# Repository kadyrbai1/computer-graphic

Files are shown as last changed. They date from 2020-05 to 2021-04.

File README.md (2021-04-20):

<p align="center">
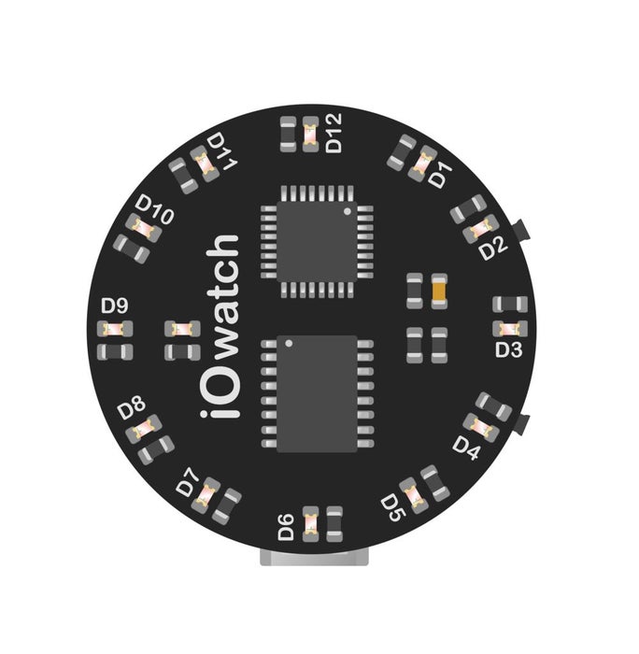
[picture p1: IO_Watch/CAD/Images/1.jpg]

</p>
<h1 align="center"><b>IO Watch</b></h3>

## ⌨️ Collaborators
- Kadyrbai Aitbaev
- Nasip Salmakhunov

## 🔗 Usefull links
- [Thingiverse](https://www.thingiverse.com/thing:4365258/files)

## Device Requirements
<h3>An overview of what components and tools were used in this build.</h3>

 - Microcontroller
  <p>The IC on this board is the ATMega328. </p>
  
 - Power system
  <p>The watch has a battery holder for a 3V, 20mm coin cell battery. Recommended 250mAh at 3V. </p>
  
 - Keeping the time
  <p>Size 0603 RED led's coupled with fairly high value (680 Ohm) resistors keeping the current low and still visible in direct sunlight. </p>
  
 - User interface
  <p>he finest RTC I can get is DS3231 keeping the time precise as it gets.  </p>
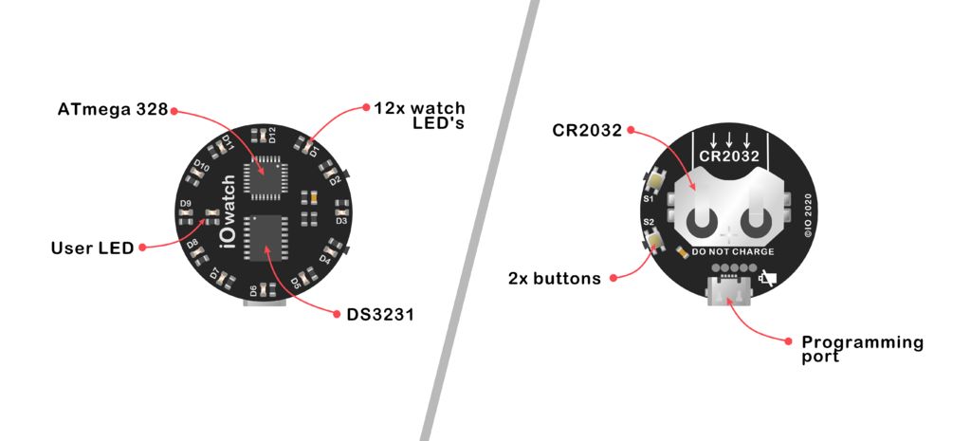
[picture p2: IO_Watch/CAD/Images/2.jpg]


## PCB - Schematics and Layout

#### PCB specifications

- Layers:2
- Dimension:35mm*35mm
- Thickness:0.8
- Impedance: no
- PCB Color: Black
- Surface Finish: HASL(with lead)
- Copper Weight:1 oz
- Gold Fingers: No
- Material Details: FR4-Standard Tg 130-140C
- Panel By JLCPCB: No
- Flying Probe Test: Fully
- Test Castellated Holes: no
<p align="center">

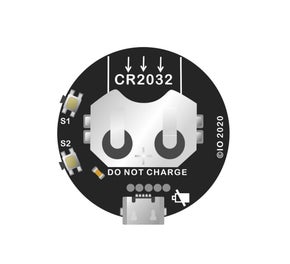
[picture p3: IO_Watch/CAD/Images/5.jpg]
 
</p>

## Programming
<p>Using the FTDI test (connection) pads provided on the back of the PCB you can use a cheap FTDI converter to upload the code.</p>
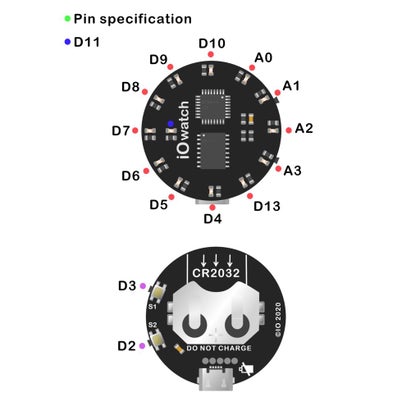
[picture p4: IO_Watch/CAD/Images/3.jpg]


## 3D Modeling and Printing
<p>verything except wrist watch band and glass - 3D prints, That includes
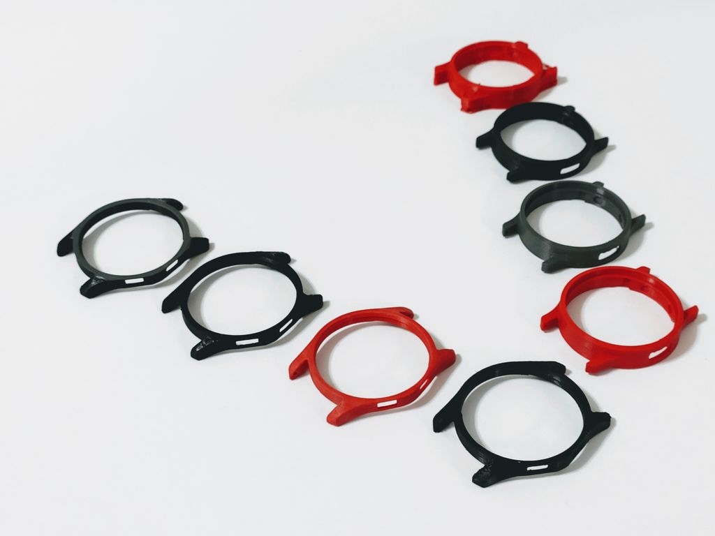
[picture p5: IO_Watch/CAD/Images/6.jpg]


- Main body
- Outer Glass ring
- Bottom body
- Buttons
I used the following settings in Cura for my prints:

- 3D Printer - Prusa I3 MK3S
- Material: PLA
- Layer Height - 0.1 mm
- Shell Thickness - 0.8 mm (Nozzle: 0.4 - 2 Shells)
- Top and Bottom Thickness - 0.8mm
- Fill Density - 100%
- Filament - 1.75mm
- Support Type - Everywhere
- Platform adhesion Type - Skirt</p>

## Circuit
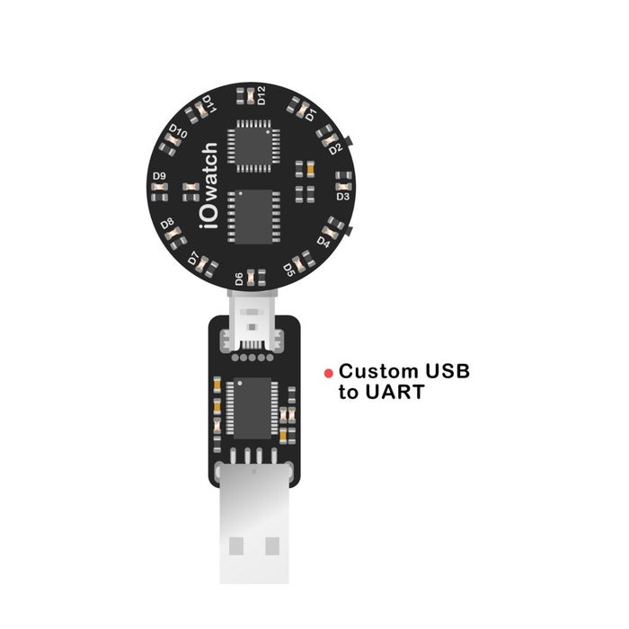
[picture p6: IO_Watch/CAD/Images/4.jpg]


## Product

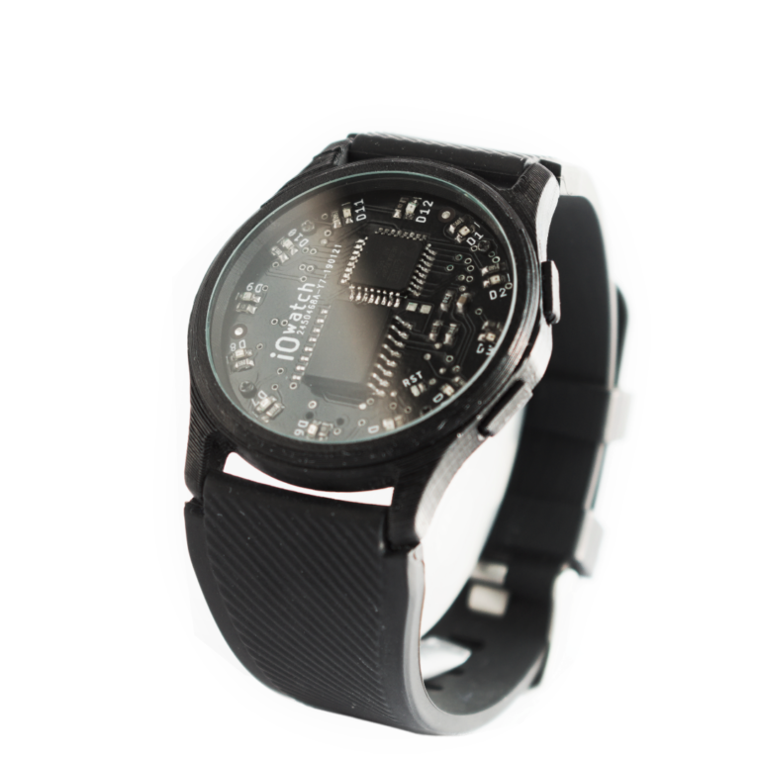
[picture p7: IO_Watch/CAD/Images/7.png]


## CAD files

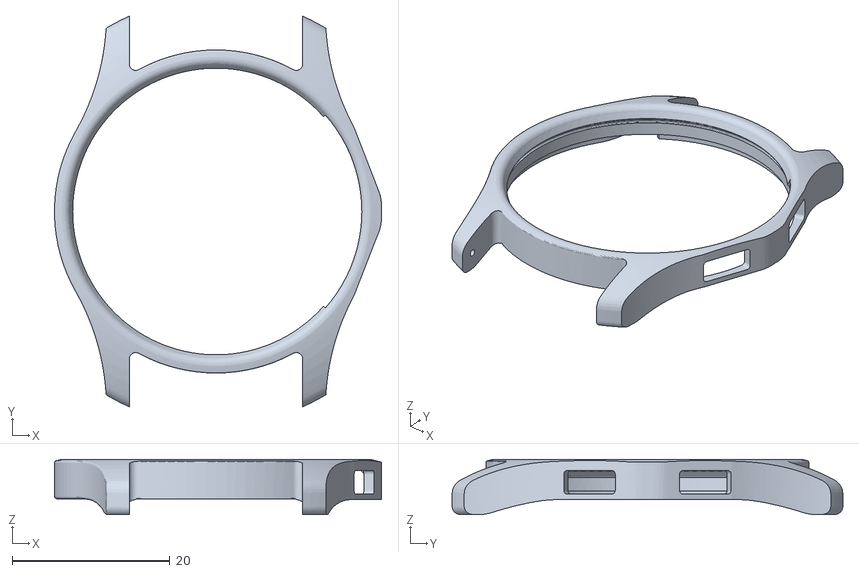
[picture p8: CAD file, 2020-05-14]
IO_Watch/CAD/Scad/imports/MainBody.stl
41.5 x 49.6 x 7.00

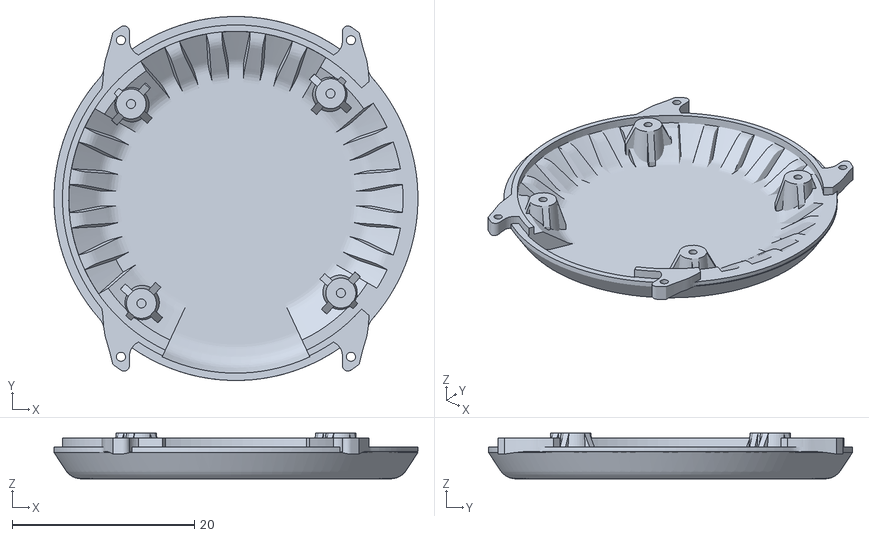
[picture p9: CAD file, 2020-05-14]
IO_Watch/CAD/Scad/imports/BottomBody.stl
40.0 x 40.0 x 5.02

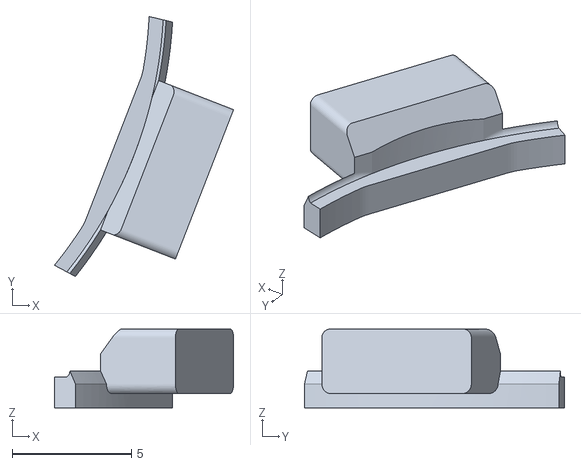
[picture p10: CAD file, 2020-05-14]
IO_Watch/CAD/Scad/imports/Button.stl
7.51 x 10.9 x 3.30

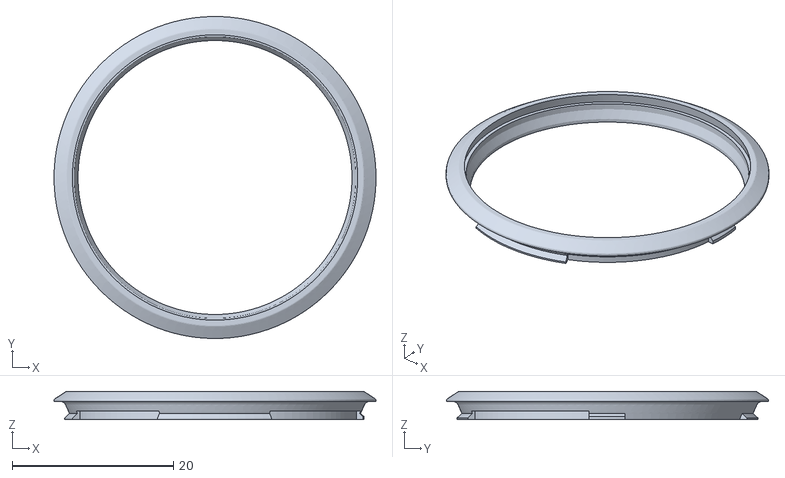
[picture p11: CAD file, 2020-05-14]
IO_Watch/CAD/Scad/imports/OuterGlassRing.stl
40.0 x 40.0 x 3.53

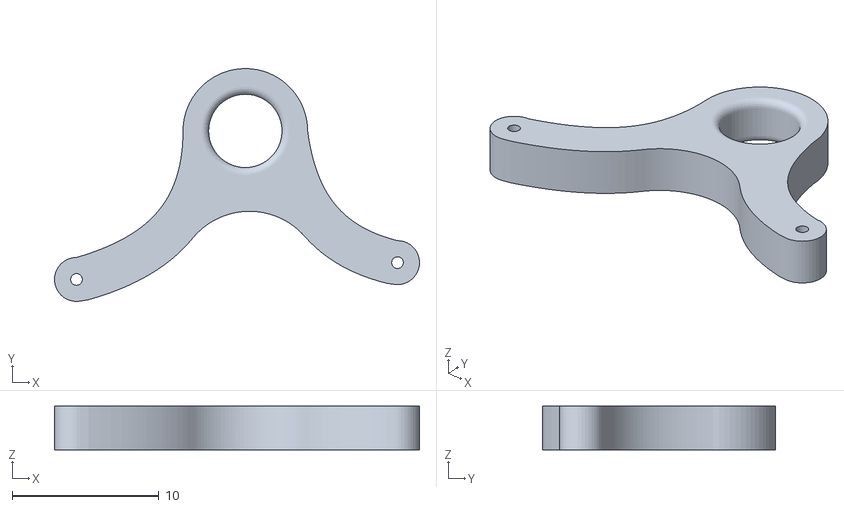
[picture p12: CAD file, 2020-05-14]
IO_Watch/CAD/Scad/imports/Badge.stl
24.9 x 15.9 x 3.00

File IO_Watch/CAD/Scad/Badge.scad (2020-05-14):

import("./imports/Badge.stl");

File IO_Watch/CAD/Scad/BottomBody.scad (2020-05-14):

import("./imports/BottomBody.stl");

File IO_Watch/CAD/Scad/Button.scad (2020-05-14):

import("Button.stl");

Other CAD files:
IO_Watch/CAD/Scad/MainBody.scad
IO_Watch/CAD/Scad/OuterGlassRing.scad

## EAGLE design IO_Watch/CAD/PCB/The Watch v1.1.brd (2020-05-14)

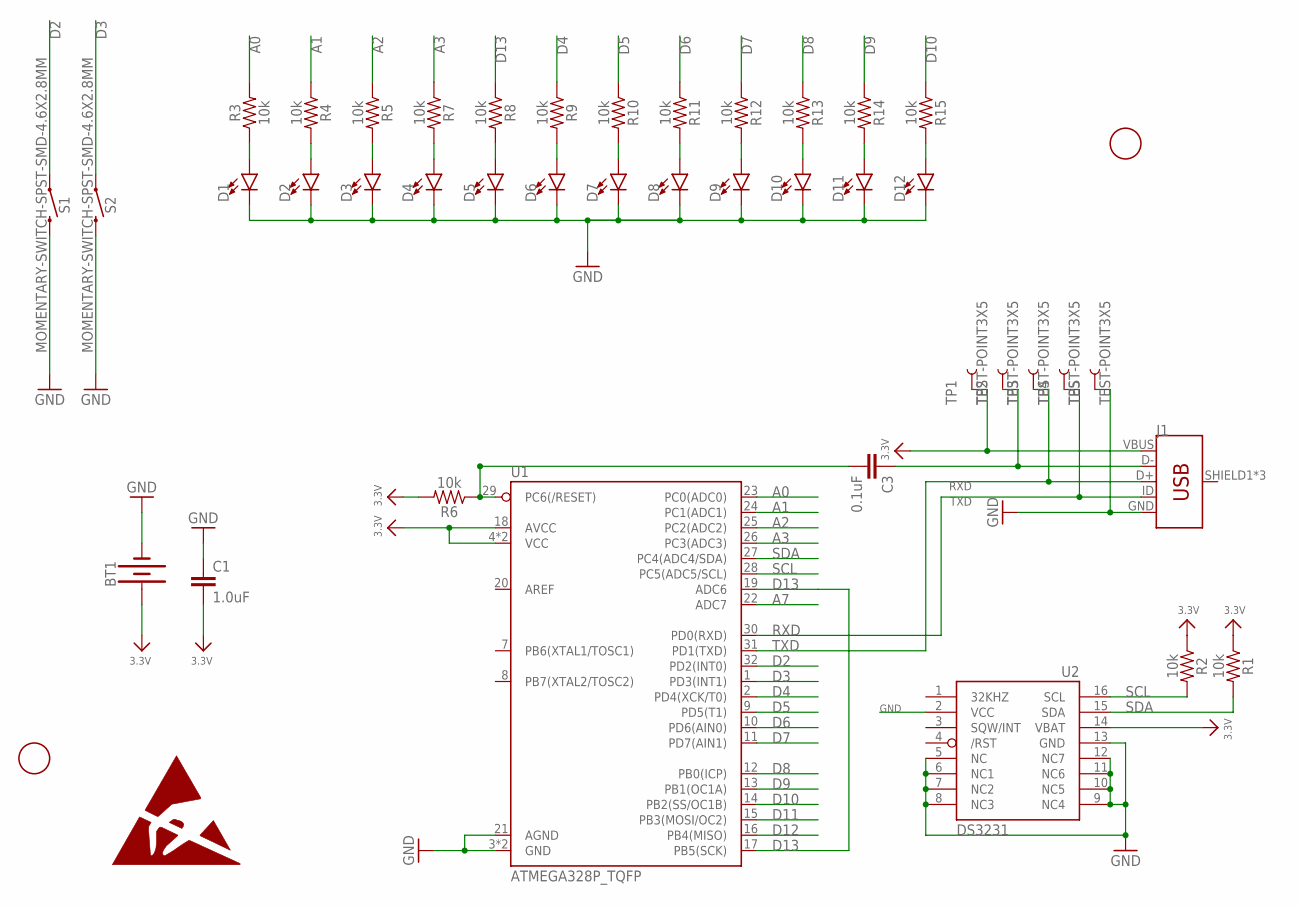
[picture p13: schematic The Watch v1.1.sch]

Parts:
BT1: BATTERY-20MM_SMD_4LEGS_OVERPASTE; BATTCON_20MM_4LEGS_OVERPASTE
C1: 1.0uF; 0603
C3: 0.1uF; 0603
D1, D2, D3, D4, D5, D6, D7, D8, D9, D10, D11, D12: LED0603; LED-0603
J1: USB_MICRO-B_FEMALE-SMT; USB-B-MICRO-SMD
R1, R2, R3, R4, R5, R6, R7, R8, R9, R10, R11, R12, R13, R14, R15: 10k; 0603
S1, S2: MOMENTARY-SWITCH-SPST-SMD-4.6X2.8MM; TACTILE_SWITCH_SMD_4.6X2.8MM
TP1, TP2, TP3, TP4, TP5: TEST-POINT3X5; PAD.03X.05
U1: ATMEGA328P_TQFP; TQFP32-08
U2: DS3231/SO; SO16W
U$1, U$10: FIDUCIAL; FIDUCIAL_1MM

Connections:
3.3V: BT1.1 (+), C1.2, J1.VBUS, R1.1, R2.1, R6.2, TP1.P$1, U1.4 (VCC), U1.6 (VCC), U1.18 (AVCC), U2.14 (VBAT)
A0: R3.2, U1.23 (PC0(ADC0))
A1: R4.1, U1.24 (PC1(ADC1))
A2: R5.1, U1.25 (PC2(ADC2))
A3: R7.1, U1.26 (PC3(ADC3))
A7: U1.22 (ADC7)
D2: S1.1, S1.2 (1), U1.32 (PD2(INT0))
D3: S2.1, S2.2 (1), U1.1 (PD3(INT1))
D4: R9.1, U1.2 (PD4(XCK/T0))
D5: R10.1, U1.9 (PD5(T1))
D6: R11.1, U1.10 (PD6(AIN0))
D7: R12.1, U1.11 (PD7(AIN1))
D8: R13.1, U1.12 (PB0(ICP))
D9: R14.1, U1.13 (PB1(OC1A))
D10: R15.1, U1.14 (PB2(SS/OC1B))
D11: U1.15 (PB3(MOSI/OC2))
D12: U1.16 (PB4(MISO))
D13: R8.1, U1.17 (PB5(SCK)), U1.19 (ADC6)
GND: BT1.2 (-), C1.1, D1.C, D2.C, D3.C, D4.C, D5.C, D6.C, D7.C, D8.C, D9.C, D10.C, D11.C, D12.C, J1.GND, S1.3 (2), S1.4 (2), S2.3 (2), S2.4 (2), TP5.P$1, U1.3 (GND), U1.5 (GND), U1.21 (AGND), U2.2 (VCC), U2.5 (NC), U2.6 (NC1), U2.7 (NC2), U2.8 (NC3), U2.9 (NC4), U2.10 (NC5), U2.11 (NC6), U2.12 (NC7), U2.13 (GND)
unnamed: D1.A, R3.1
unnamed: D2.A, R4.2
unnamed: D3.A, R5.2
unnamed: D4.A, R7.2
unnamed: D5.A, R8.2
unnamed: D6.A, R9.2
unnamed: D7.A, R10.2
unnamed: D8.A, R11.2
unnamed: D9.A, R12.2
unnamed: D10.A, R13.2
unnamed: D11.A, R14.2
unnamed: D12.A, R15.2
unnamed: C3.1, J1.D-, TP2.P$1
RESET: C3.2, R6.1, U1.29 (PC6(/RESET))
RXD: J1.ID, TP4.P$1, U1.30 (PD0(RXD))
SCL: R2.2, U1.28 (PC5(ADC5/SCL)), U2.16 (SCL)
SDA: R1.2, U1.27 (PC4(ADC4/SDA)), U2.15 (SDA)
TXD: J1.D+, TP3.P$1, U1.31 (PD1(TXD))

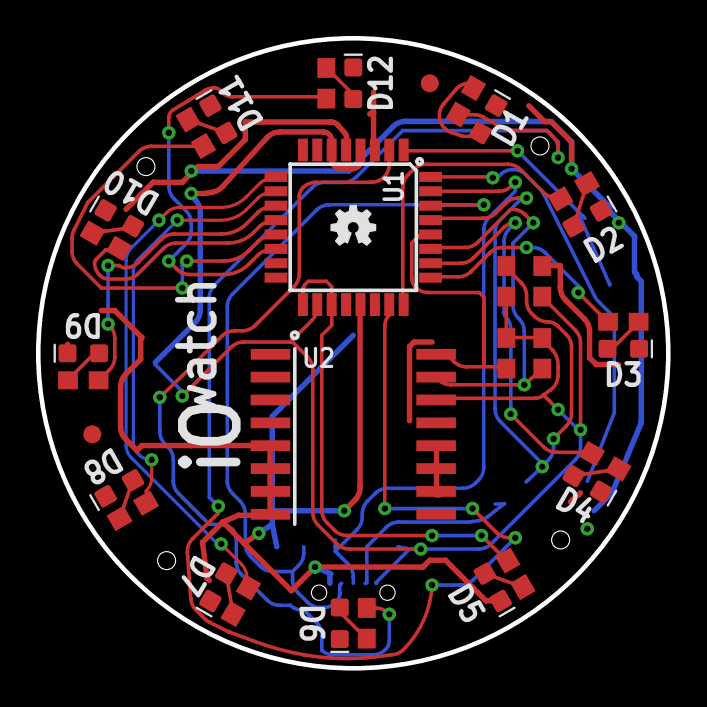
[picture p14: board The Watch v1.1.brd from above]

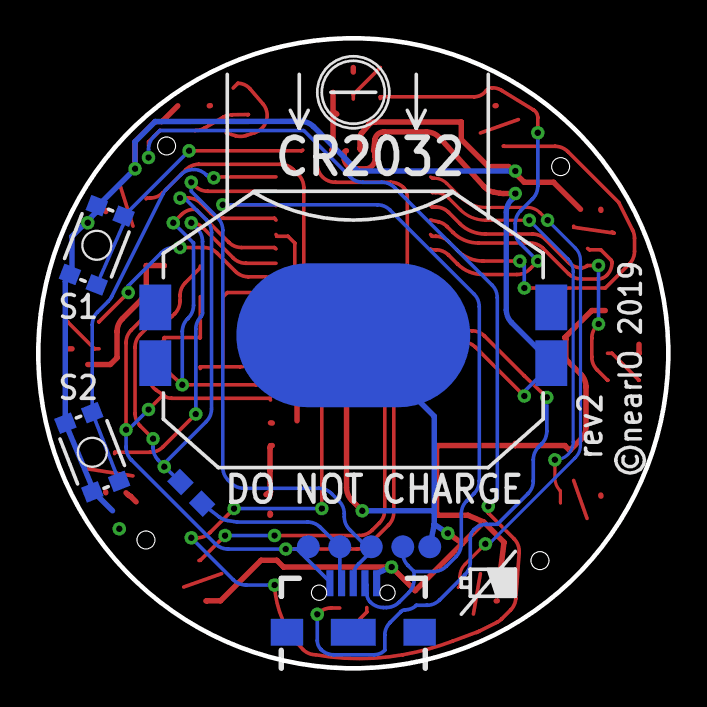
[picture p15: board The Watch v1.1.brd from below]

Board: 2 copper layers, 35.0 x 35.0 mm, 43 parts (10 on the bottom side), 34 nets.

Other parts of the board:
U$6: OSHW-LOGO-MINI

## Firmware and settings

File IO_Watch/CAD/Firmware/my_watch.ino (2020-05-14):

#include <Wire.h>                    // library for communication with I2C - DS3231
                                     // https://www.arduino.cc/en/Reference/Wire
#include "RTClib.h"                  // library for Real Time Clock
                                     // https://github.com/adafruit/RTClib.git
#include "LowPower.h"                // library for deep sleep
                                     // https://github.com/rocketscream/Low-Power.git
#include "OneButton.h"               // library for button (short press /double press /long press)
                                     // https://github.com/mathertel/OneButton.git


RTC_DS3231 rtc;                      // RealTimeClock object

byte hours;                          // hours variable       
byte minutesFive;                    // minutes variable
byte minutesOne;                     // minutes variable
byte minutesOnFive;                  // minutes variable
byte temperatures;                   // temperature variable
byte temperaturesOnFive;             // temperature variable

byte settingHours = 0;               // variable initialization
byte settingMinutes = 0;             // variable initialization
byte settingMinutesToFive = 0;       // variable initialization

const byte leds[] = {10, A0, A1, A2, A3, 13, 4, 5, 6, 7, 8, 9};  // 12 LED's array pin assigning
const byte LEDS_SIZE = sizeof(leds)/sizeof(leds[0]);

static byte buttonPin = 2;                           // assigning button pin value
static byte buttonPin2 = 3;                           // assigning button pin value

static byte userLed = 11;

boolean timeSettingMode = false;               // time setting mode
boolean timeSettingModeHours = false;          // time setting mode hours [0, 11]
boolean timeSettingModeMinutes = false;        // time setting mode minutes [0, 5, 10, .., 55]
boolean timeSettingModeMinutesToFive = false;  // time setting mode minutes [0-4]

OneButton button(3, true);      // button
OneButton button2(2, true);      // button

void setup () {
  Serial.begin(9600);         //enabling serial communication at 9600 boud rate

  //rtc.adjust(DateTime(F(__DATE__), F(__TIME__)));    // following line sets the RTC to the date & time this sketch was compiled
  rtc.adjust(DateTime(2019, 1, 1, 0, 0, 0));           //year, month, day, hour, minute, second

  for (int i=0; i<LEDS_SIZE; i++){
    pinMode(leds[i], OUTPUT);             // assigning all pins in array as output
  }
  pinMode(userLed, OUTPUT);             // assigning all pins in array as output

  allOn();          //bootup all LED's turning
  allOff();         //turning all LED's off

  delay(40);

  attachInterrupt(0, wakeFunction, FALLING);        //interrupt for waking up
  attachInterrupt(1, wakeFunction, FALLING);        //interrupt for waking up
  
  //button.attachDoubleClick(doubleclick);            // link the function to be called on a doubleclick event.
  button.attachClick(singleclick);                  // link the function to be called on a singleclick event.
  button.attachLongPressStop(longclick);            // link the function to be called on a longpress event.
  
  //button2.attachDoubleClick(doubleclick);            // link the function to be called on a doubleclick event.
  button2.attachClick(singleclick2);                  // link the function to be called on a singleclick event.
  //button2.attachLongPressStop(longclick);            // link the function to be called on a longpress event.
  
  shutdownNow();      //calling deep sleep function
}

void loop (){
  
   button.tick();     //checking if button is pressed and long
   delay(10);         //needed for stable operation and for button ticking
   button2.tick();     //checking if button 2 is pressed and long
   Serial.println("Tick");
   
}

void wakeFunction(){  //interrupt function when button is presse
  
}

void singleclick(){   //single Click button
  
 if(!timeSettingMode){

    unsigned int DelayHoursLedON = 500;           // how long will hour LED light up after getting time (in microseconds)
    unsigned int DelayHoursLedOFF = 300;          // how long will hour LED stay off after showing time (in microseconds)
    unsigned int DelayMinutesLedON = 150;         // how long will minutes LED light up after getting time in microseconds
    unsigned int DelayMinutesLedOFF = 280;        // how long will minutes LED stay off after showing time in microseconds
    
    DateTime now = rtc.now();     //gets the current time from DST

    hours = now.hour();

    minutesOne = now.minute();
    minutesFive = minutesOne/5;

    if(hours >= 12){
      hours = hours - 12;
    }
      
    digitalWrite(leds[hours],HIGH);
    delay(DelayHoursLedON);
    digitalWrite(leds[hours],LOW);
    delay(DelayHoursLedOFF);
  
    digitalWrite(leds[minutesFive],HIGH);
    delay(DelayHoursLedON);
    digitalWrite(leds[minutesFive],LOW);
    delay(DelayHoursLedOFF);
            
     minutesOnFive = minutesOne - (minutesFive * 5);
          
    for (int i=1; i <= minutesOnFive ; i++){   
       digitalWrite(leds[i], HIGH);
       delay(DelayMinutesLedOFF);
    } 
    for (int i=1; i <= minutesOnFive ; i++){       
      digitalWrite(leds[i], LOW);
      delay(DelayMinutesLedON);
    }
   shutdownNow();
 }else{
  if(timeSettingModeHours){         //hours scrolling trough LED's
    digitalWrite(leds[settingHours], LOW);
    if(settingHours == 0){
      settingHours = 11;
      digitalWrite(leds[settingHours], HIGH);
    }else{
      settingHours--;
      digitalWrite(leds[settingHours], HIGH);
    }
  }
  if(timeSettingModeMinutes){       //minutes scrolling trough LED's
    digitalWrite(leds[settingMinutes], LOW);
    if(settingMinutes == 0){
      settingMinutes = 11;
      digitalWrite(leds[settingMinutes], HIGH);
    }else{
      settingMinutes--;
      digitalWrite(leds[settingMinutes], HIGH);
    }
  }
  if(timeSettingModeMinutesToFive){       //minutes to five scrolling trough LED's
    digitalWrite(leds[settingMinutesToFive], LOW);
    if(settingMinutesToFive == 0){
      settingMinutesToFive = 4;
      digitalWrite(leds[settingMinutesToFive], HIGH);
    }else{
      settingMinutesToFive--;
      digitalWrite(leds[settingMinutesToFive], HIGH);
    }
  }
 }
}

void singleclick2(){   //single Click button
 if(!timeSettingMode){

    allOff();         //turning all LED's off

    digitalWrite(userLed, HIGH);
      
    temperatures = rtc.getTemperature();
    temperaturesOnFive = temperatures / 5;
    for (int i=0; i <= temperaturesOnFive ; i++){ 
      digitalWrite(leds[i], HIGH);
      delay(500);
    } 
    for (int i=0; i <= temperaturesOnFive ; i++){  
     digitalWrite(leds[i], LOW);
     delay(200);
    }
    delay(500);
    temperatures = temperatures - (temperaturesOnFive * 5);
    for (int i=1; i <= temperatures ; i++){
      digitalWrite(leds[i], HIGH);
      delay(500);
    }
    for (int i=1; i <= temperatures ; i++){       
     digitalWrite(leds[i], LOW);
     delay(200);
    }
    
     shutdownNow();
 }else{
  if(timeSettingModeHours){         //hours scrolling trough LED's
    digitalWrite(leds[settingHours], LOW);
    if(settingHours == 11){
      settingHours = 0;
      digitalWrite(leds[settingHours], HIGH);
    }else{
      settingHours++;
      digitalWrite(leds[settingHours], HIGH);
    }
  }
  if(timeSettingModeMinutes){       //minutes scrolling trough LED's
    digitalWrite(leds[settingMinutes], LOW);
    if(settingMinutes == 11){
      settingMinutes = 0;
      digitalWrite(leds[settingMinutes], HIGH);
    }else{
      settingMinutes++;
      digitalWrite(leds[settingMinutes], HIGH);
    }
  }
  if(timeSettingModeMinutesToFive){       //minutes to five scrolling trough LED's
    digitalWrite(leds[settingMinutesToFive], LOW);
    if(settingMinutesToFive == 4){
      settingMinutesToFive = 0;
      digitalWrite(leds[settingMinutesToFive], HIGH);
    }else{
      settingMinutesToFive++;
      digitalWrite(leds[settingMinutesToFive], HIGH);
    }
  }
 }
}

void longclick(){         //longclick function for time setting
  
  if(timeSettingModeMinutesToFive && !timeSettingModeMinutes){
    timeSettingModeMinutes = true;  // pass
  }
 
  if(timeSettingMode){
    if(timeSettingModeMinutes){
      if(timeSettingModeMinutesToFive){
        rtc.adjust(DateTime(2018, 12, 16, settingHours, (settingMinutes *5) + settingMinutesToFive,0 )); // setting desiered time
        /*
        Serial.print("Changing TIME to ");
        Serial.print(settingHours);
        Serial.print("h ");
        Serial.print((settingMinutes*5)+settingMinutesToFive);
        Serial.println("min ");
        */
        timeSettingMode = false;                  // exiting timeSetting MODE
        timeSettingModeMinutesToFive = false;     // exiting minutes to five MENU
        timeSettingModeMinutes = false;           // exiting minutes MENU
        settingMinutesToFive = 0;                 // reseting MinutesToFive
        settingMinutes = 0;                       // reseting Minutes
        settingHours = 0;                         // reseting hours
        allOn();                                  // turning all LED's on
        allOff();                                 // turning all LED's off
        singleclick();                            // showing time
        
      }else{
        timeSettingModeMinutesToFive = true;      // entering minutesToFive MENU (rest of the minutes)
        timeSettingModeMinutes = false;           // exiting minutes MENU
        allOff();                                 // turning all LED's off
        digitalWrite(leds[settingMinutesToFive], HIGH);
      }
    }else{
     timeSettingModeMinutes = true;     // entering minutes MENU
     timeSettingModeHours = false;      // exiting hours MENU
     allOff();          //turning all LED's off
     digitalWrite(leds[settingMinutes], HIGH);
    }
    }else{
    timeSettingMode = true;         // activating timeSetting mode
    timeSettingModeHours = true;    // entering hours MENU
    digitalWrite(leds[settingHours], HIGH);
  }
}

void allOff(){
  for (int i=0; i<LEDS_SIZE; i++){
    digitalWrite(leds[i], LOW);       //turning all LED's off
  }
  digitalWrite(userLed, LOW);
}

void allOn(){         //function turning all LED's on in specific pattern
   for (int i=0; i<LEDS_SIZE; i++){
    digitalWrite(leds[i], HIGH);       //turning all LED's off
    delay(100);
  }  
}

void shutdownNow(){
    allOff();
    Serial.println("going to sleep");
    delay(500);
    LowPower.powerDown(SLEEP_FOREVER, ADC_OFF, BOD_OFF); //deep sleep
}

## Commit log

2020-05-14 Body stl
    [Badge.stl, MainBody.stl]
2020-05-14 Bottom stl
    [BottomBody.stl, Button.stl, OuterGlassRing.stl]
2020-05-14 scad files
    [Badge.scad, Badge.stl, BottomBody.scad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]

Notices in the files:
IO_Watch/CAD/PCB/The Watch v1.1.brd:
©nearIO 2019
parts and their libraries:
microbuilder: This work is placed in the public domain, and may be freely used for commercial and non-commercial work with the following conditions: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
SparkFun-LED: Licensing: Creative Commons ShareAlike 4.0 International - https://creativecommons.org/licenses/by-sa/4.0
